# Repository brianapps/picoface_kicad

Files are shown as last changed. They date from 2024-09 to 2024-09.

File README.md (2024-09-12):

# picoFace KiCad

The picoFace is an inexpensive device for the Sinclair ZX Spectrum that use a Raspberry Pi Pico to provide a Multiface style support. 

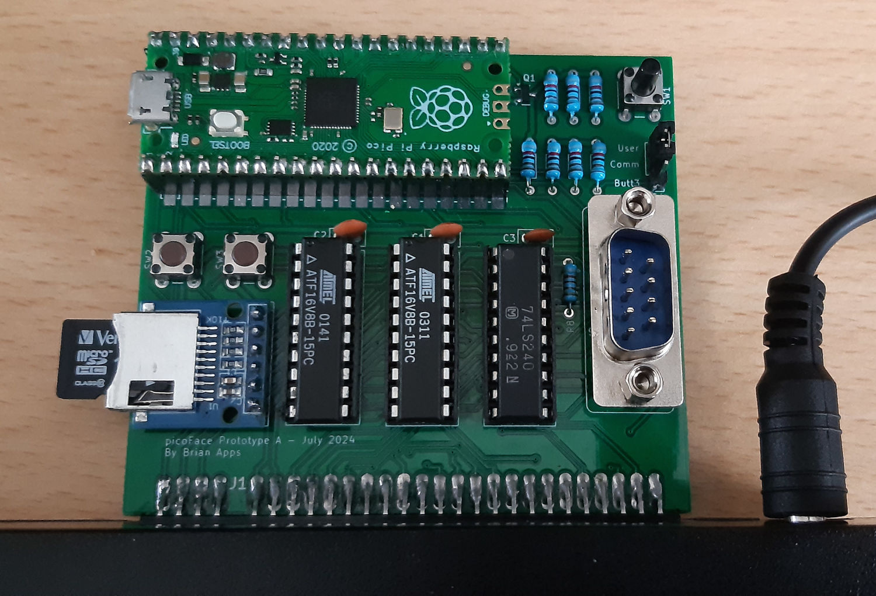
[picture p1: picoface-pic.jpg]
picoFace Pic


See the main picoFace repository for more info https://github.com/brianapps/picoface_poc.

## Info

The circuit board is relatively simple.

The two ATF16V8B chips are programmed with logic provided in the [main picoFace repo](https://github.com/brianapps/picoface_poc).

The design uses a number of custom symbols:
* A modified RPi Pico part without the debug pins on the footprint.
* A custom part for the SD module to match a very cheap and generic one from AliExpress.
* Symbols for the two PLDs. These are updated automatically using a Python script from the [main repo](https://github.com/brianapps/picoface_poc).

## License

picoFace is free software: you can redistribute it and/or modify it under the terms of
the GNU General Public License as published by the Free Software Foundation, either
version 3 of the License, or (at your option) any later version.

picoFace is distributed in the hope that it will be useful, but WITHOUT ANY WARRANTY; 
without even the implied warranty of MERCHANTABILITY or FITNESS FOR A PARTICULAR PURPOSE.
See the GNU General Public License for more details.

A copy of the license is provided in the [LICENSE](./LICENSE) file.

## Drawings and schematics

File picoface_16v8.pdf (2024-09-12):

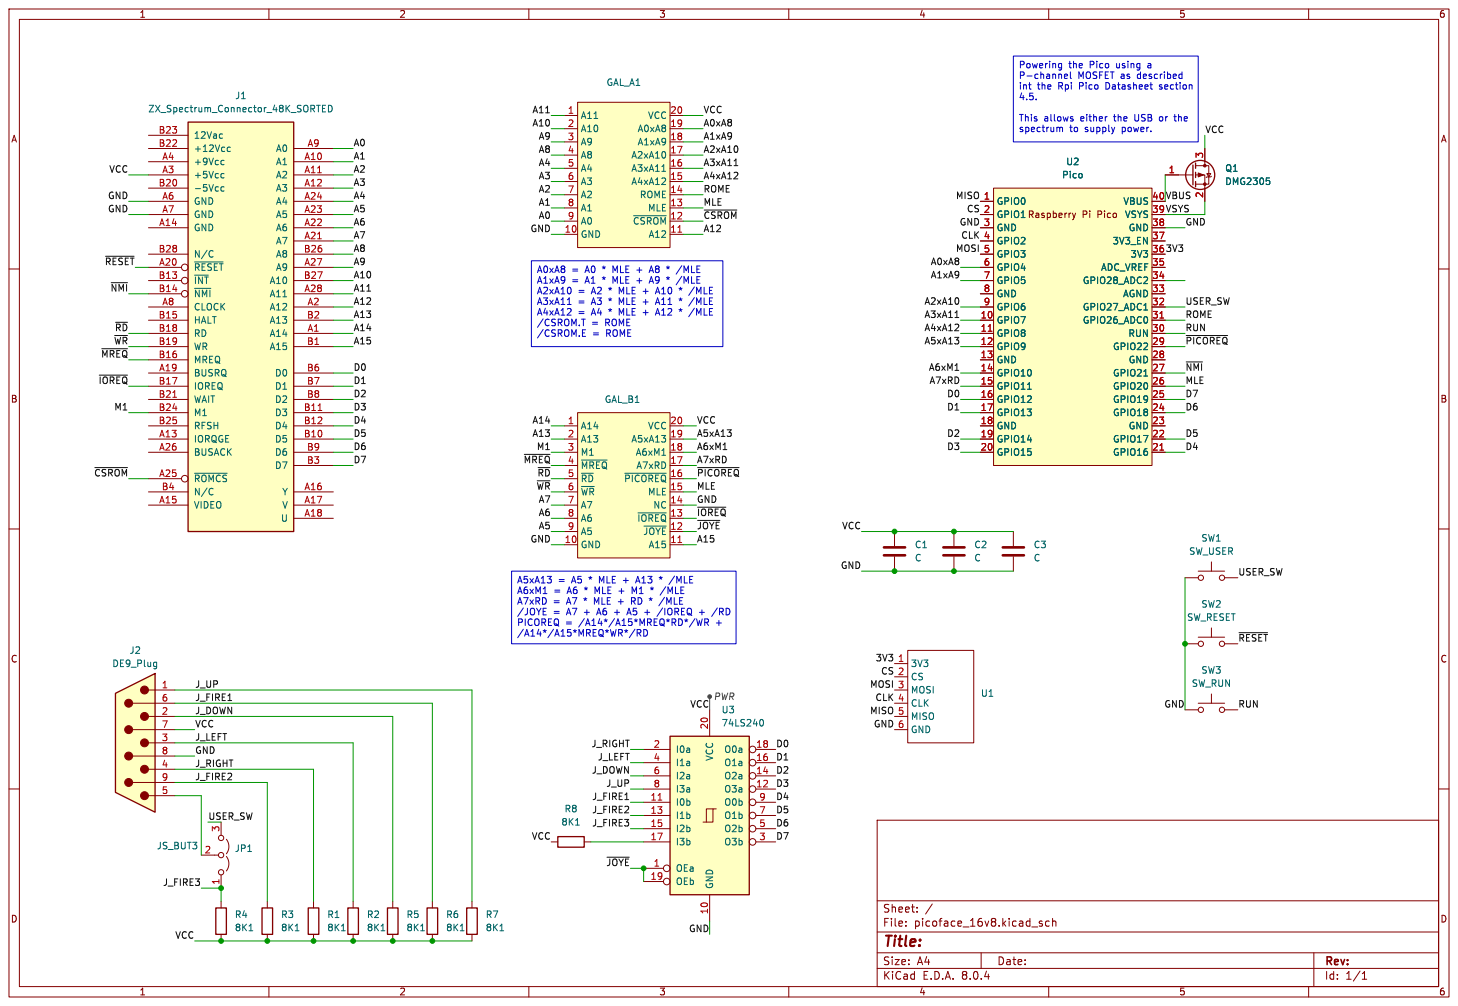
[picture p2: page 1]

4.5. This allows either the USB or the

Id: 1/1 Title: File: picoface_16v8.kicad_sch Sheet: / R5

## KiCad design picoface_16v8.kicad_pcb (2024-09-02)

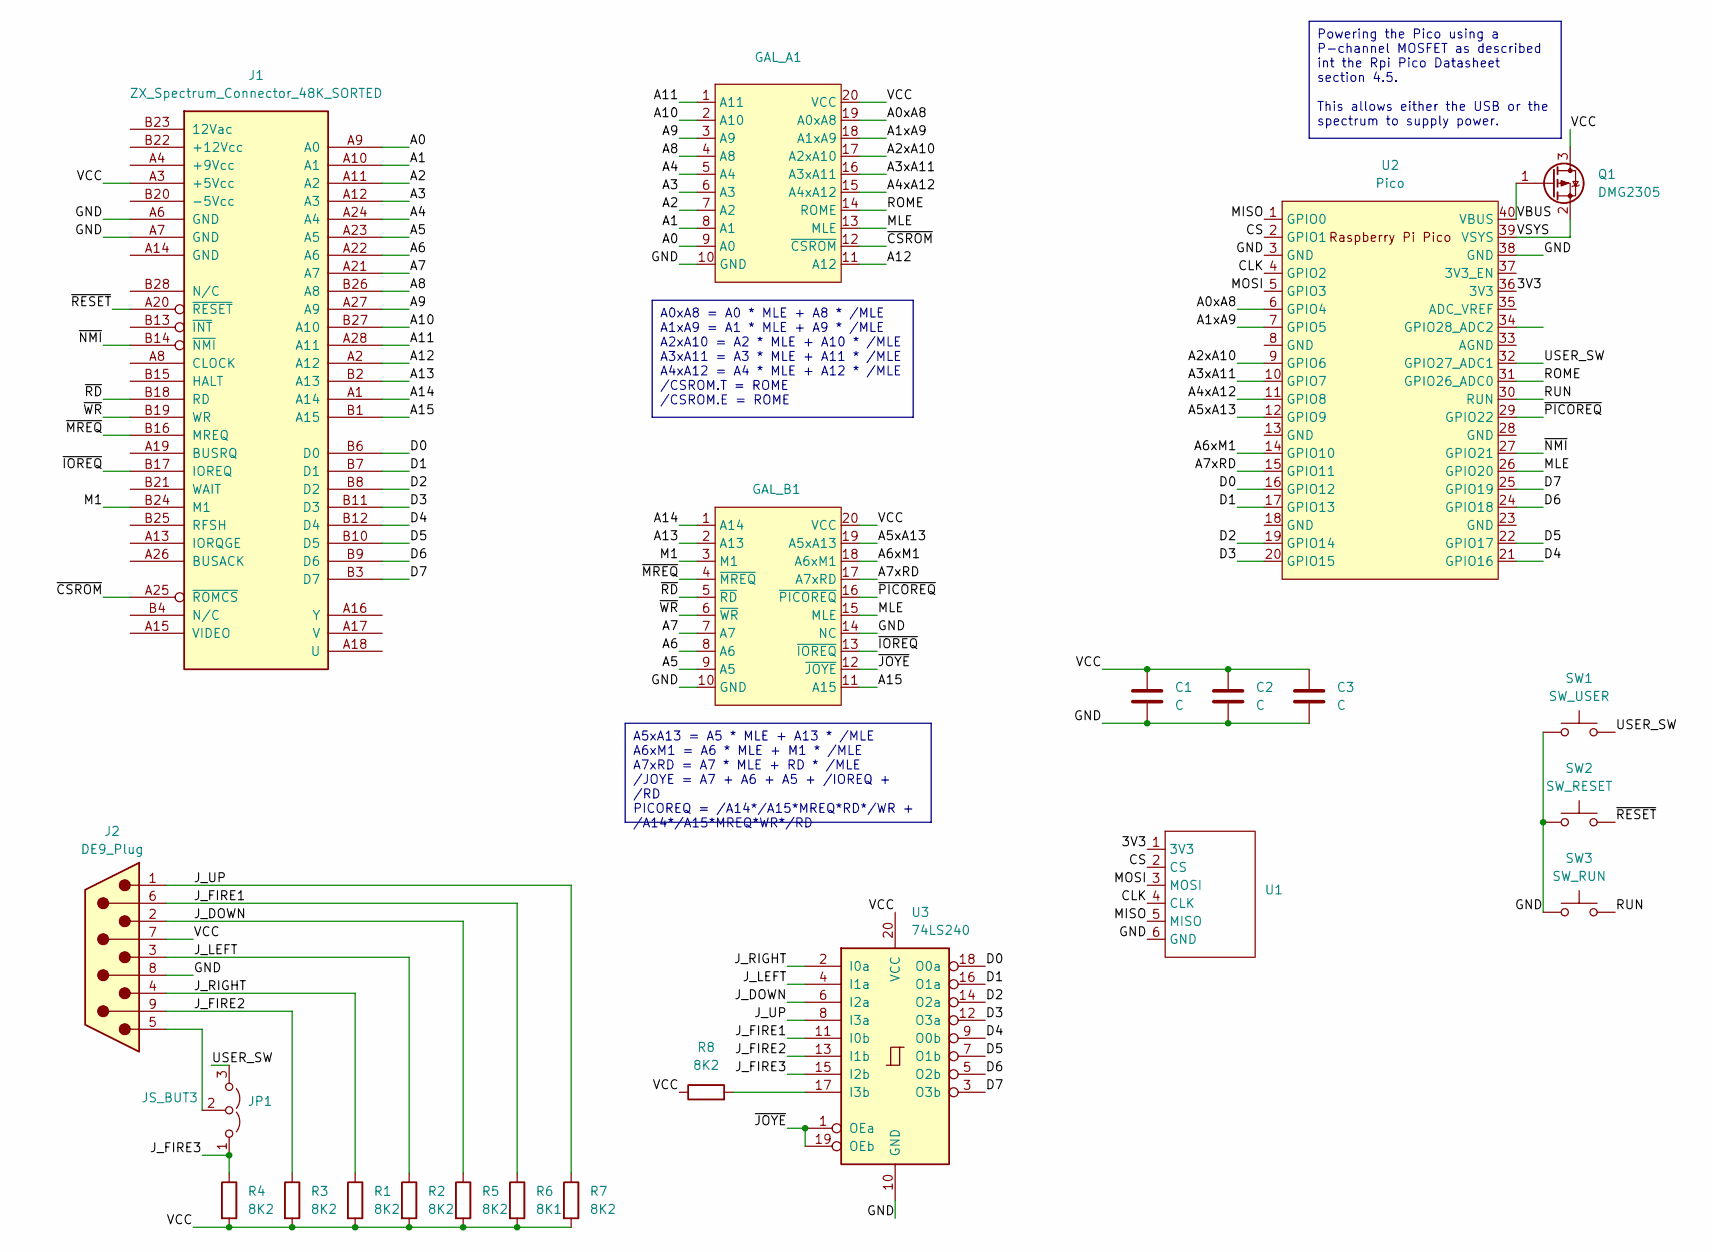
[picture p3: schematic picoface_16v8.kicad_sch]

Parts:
C1, C2, C3: C; C_Disc_D5.0mm_W2.5mm_P2.50mm
GAL_A1: DIP-20_W7.62mm_Socket
GAL_B1: DIP-20_W7.62mm_Socket
J1: ZX_Spectrum_Connector_48K_SORTED; ZX_CONN
J2: DE9_Plug; DSUB-9_Female_Vertical_P2.77x2.84mm_MountingHoles
JP1: JS_BUT3; PinHeader_1x03_P2.54mm_Vertical
Q1: DMG2305; SOT-23
R1, R2, R3, R4, R5, R7, R8: 8K2; R_Axial_DIN0204_L3.6mm_D1.6mm_P7.62mm_Horizontal
R6: 8K1; R_Axial_DIN0204_L3.6mm_D1.6mm_P7.62mm_Horizontal
SW1: SW_USER; SW_PUSH_6mm_H8mm
SW2: SW_RESET; SW_PUSH_6mm_H8mm
SW3: SW_RUN; SW_PUSH_6mm_H8mm
U1: SDMICRO_ALIEXPRESS
U2: Pico; RPi_Pico_SMD_TH_BA
U3: 74LS240; DIP-20_W7.62mm_Socket

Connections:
/3V3: U1.1 (3V3), U2.36 (3V3)
/A0: GAL_A1.9 (A0), J1.A9 (A0)
/A0xA8: GAL_A1.19 (A0xA8), U2.6 (GPIO4)
/A1: GAL_A1.8 (A1), J1.A10 (A1)
/A1xA9: GAL_A1.18 (A1xA9), U2.7 (GPIO5)
/A2: GAL_A1.7 (A2), J1.A11 (A2)
/A2xA10: GAL_A1.17 (A2xA10), U2.9 (GPIO6)
/A3: GAL_A1.6 (A3), J1.A12 (A3)
/A3xA11: GAL_A1.16 (A3xA11), U2.10 (GPIO7)
/A4: GAL_A1.5 (A4), J1.A24 (A4)
/A4xA12: GAL_A1.15 (A4xA12), U2.11 (GPIO8)
/A5: GAL_B1.9 (A5), J1.A23 (A5)
/A5xA13: GAL_B1.19 (A5xA13), U2.12 (GPIO9)
/A6: GAL_B1.8 (A6), J1.A22 (A6)
/A6xM1: GAL_B1.18 (A6xM1), U2.14 (GPIO10)
/A7: GAL_B1.7 (A7), J1.A21 (A7)
/A7xRD: GAL_B1.17 (A7xRD), U2.15 (GPIO11)
/A8: GAL_A1.4 (A8), J1.B26 (A8)
/A9: GAL_A1.3 (A9), J1.A27 (A9)
/A10: GAL_A1.2 (A10), J1.B27 (A10)
/A11: GAL_A1.1 (A11), J1.A28 (A11)
/A12: GAL_A1.11 (A12), J1.A2 (A12)
/A13: GAL_B1.2 (A13), J1.B2 (A13)
/A14: GAL_B1.1 (A14), J1.A1 (A14)
/A15: GAL_B1.11 (A15), J1.B1 (A15)
/CLK: U1.4 (CLK), U2.4 (GPIO2)
/CS: U1.2 (CS), U2.2 (GPIO1)
/D0: J1.B6 (D0), U2.16 (GPIO12), U3.18 (O0a)
/D1: J1.B7 (D1), U2.17 (GPIO13), U3.16 (O1a)
/D2: J1.B8 (D2), U2.19 (GPIO14), U3.14 (O2a)
/D3: J1.B11 (D3), U2.20 (GPIO15), U3.12 (O3a)
/D4: J1.B12 (D4), U2.21 (GPIO16), U3.9 (O0b)
/D5: J1.B10 (D5), U2.22 (GPIO17), U3.7 (O1b)
/D6: J1.B9 (D6), U2.24 (GPIO18), U3.5 (O2b)
/D7: J1.B3 (D7), U2.25 (GPIO19), U3.3 (O3b)
/GND: C1.2, C2.2, C3.2, GAL_A1.10 (GND), GAL_B1.10 (GND), GAL_B1.14 (NC), J1.A6 (GND), J1.A7 (GND), J2.8, SW1.1, SW2.1, SW3.1, U1.6 (GND), U2.3 (GND), U2.38 (GND), U3.10 (GND)
/J_DOWN: J2.2, R5.1, U3.6 (I2a)
/J_FIRE1: J2.6, R6.1, U3.11 (I0b)
/J_FIRE2: J2.9, R3.1, U3.13 (I1b)
/J_FIRE3: JP1.1 (A), R4.1, U3.15 (I2b)
/J_LEFT: J2.3, R2.1, U3.4 (I1a)
/J_RIGHT: J2.4, R1.1, U3.2 (I0a)
/J_UP: J2.1, R7.1, U3.8 (I3a)
/M1: GAL_B1.3 (M1), J1.B24 (M1)
/MISO: U1.5 (MISO), U2.1 (GPIO0)
/MLE: GAL_A1.13 (MLE), GAL_B1.15 (MLE), U2.26 (GPIO20)
/MOSI: U1.3 (MOSI), U2.5 (GPIO3)
/ROME: GAL_A1.14 (ROME), U2.31 (GPIO26_ADC0)
/RUN: SW3.2, U2.30 (RUN)
/USER_SW: JP1.3 (B), SW1.2, U2.32 (GPIO27_ADC1)
/VBUS: Q1.1 (G), U2.40 (VBUS)
/VCC: C1.1, C2.1, C3.1, GAL_A1.20 (VCC), GAL_B1.20 (VCC), J1.A3 (+5Vcc), J2.7, Q1.3 (D), R1.2, R2.2, R3.2, R4.2, R5.2, R6.2, R7.2, R8.1, U3.20 (VCC)
/VSYS: Q1.2 (S), U2.39 (VSYS)
/~CSROM: GAL_A1.12 (~CSROM), J1.A25 (~ROMCS)
/~IOREQ: GAL_B1.13 (~IOREQ), J1.B17 (IOREQ)
/~JOYE: GAL_B1.12 (~JOYE), U3.1 (OEa), U3.19 (OEb)
/~MREQ: GAL_B1.4 (~MREQ), J1.B16 (MREQ)
/~NMI: J1.B14 (~NMI), U2.27 (GPIO21)
/~PICOREQ: GAL_B1.16 (~PICOREQ), U2.29 (GPIO22)
/~RD: GAL_B1.5 (~RD), J1.B18 (RD)
/~RESET: J1.A20 (~RESET), SW2.2
/~WR: GAL_B1.6 (~WR), J1.B19 (WR)
unnamed: J2.5, JP1.2 (C)
unnamed: R8.2, U3.17 (I3b)

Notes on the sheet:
Powering the Pico using a P-channel MOSFET as described int the Rpi Pico Datasheet section 4.5. This allows either the USB or the spectrum to supply power.
A0xA8 = A0 * MLE + A8 * /MLE A1xA9 = A1 * MLE + A9 * /MLE A2xA10 = A2 * MLE + A10 * /MLE A3xA11 = A3 * MLE + A11 * /MLE A4xA12 = A4 * MLE + A12 * /MLE /CSROM.T = ROME /CSROM.E = ROME
A5xA13 = A5 * MLE + A13 * /MLE A6xM1 = A6 * MLE + M1 * /MLE A7xRD = A7 * MLE + RD * /MLE /JOYE = A7 + A6 + A5 + /IOREQ + /RD PICOREQ = /A14*/A15*MREQ*RD*/WR + /A14*/A15*MREQ*WR*/RD

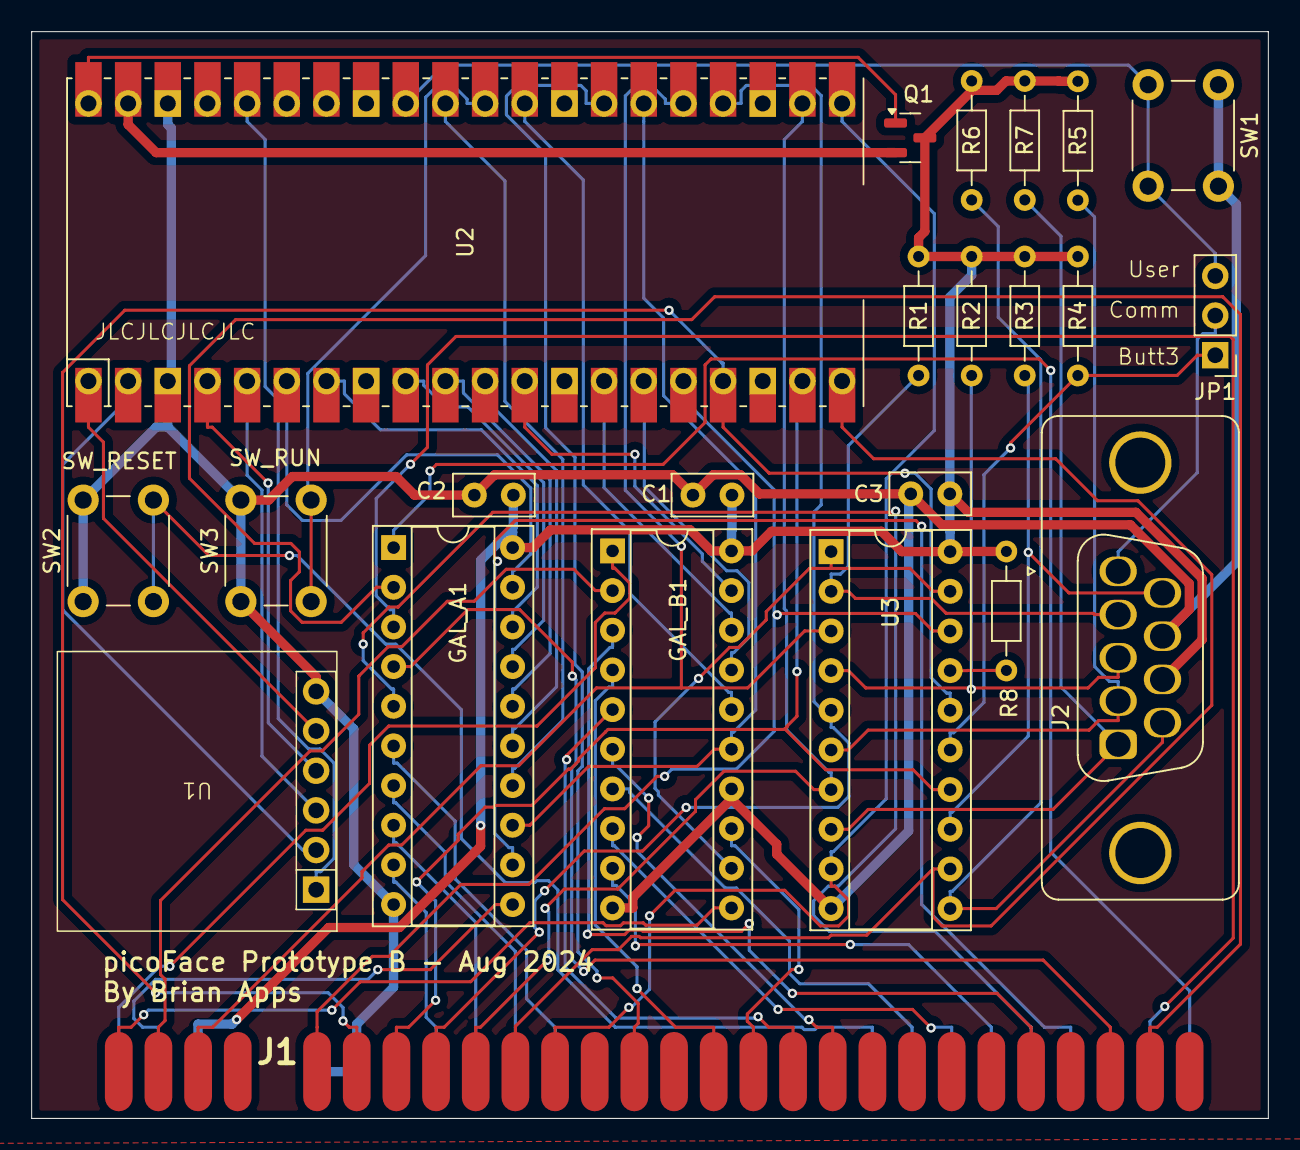
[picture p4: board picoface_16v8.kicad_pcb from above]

Board: 2 copper layers, 79.2 x 69.6 mm, 23 parts (0 on the bottom side), 64 nets.

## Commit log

2024-07-24 First prototype picoFace board
    [picoface_16v8.kicad_pcb, picoface_16v8.kicad_sch]
2024-07-25 Picoface prototype a board
    This includes the gerbers as sent to JCL PCB for the initial
    prototype board.
    [picoface_16v8.kicad_pcb]
2024-08-07 Prototype B board, fix up mistakes in prototype A
    Correct the joystick up connection, make SD card drill holes slightly larger.
    [picoface_16v8.kicad_pcb, picoface_16v8.kicad_sch]
2024-09-02 Correct resistor typo and add GALASM to schematic
    I just blindly typed in 8K1 whereas the resistor I have are 8K2.
    [picoface_16v8.kicad_pcb, picoface_16v8.kicad_sch]
2024-09-12 Add updated schematic PDF
2026-10-15 Update to KiCad 9 and add missing gerbers
    See issue #1 for details
